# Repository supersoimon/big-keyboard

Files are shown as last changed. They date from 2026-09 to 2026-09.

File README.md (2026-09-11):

# Big Keyboard Simon V2!!!!!!!
Big Keyboard is a custom tenkeyless keyboard (87 keys) designed to fit inside a fully-3d printable case. It uses a Raspberry Pi Pico W, and connects via a Micro-USB. 

# CAD
The CAD design consists of 3 layers, using dovetail joints to hold the outer, inner, and middle layers together, while also allowing them to be easily taken apart. 





# PCB
Big Keyboard's PCB has got a couple of parts to it - a Raspberry Pi Pico (no wireless) and, diodes, and keys (pretty simple). The Diodes are SMD, while the Cherry MX keys and Pi Pico are THT.





# FIRMWARE/SOFTWARE
Pretty simple firmware, used QMK (had prior experience). Haven't coded the function of the function keys (f1, f2, etc) when not in function mode, haven't decided what I want them to do.



# Changes
Pi board was changed from SMD to THT, for easier addition

# EXTRA
Originally Big Keyboard was intentended to be a 104-key keyboard, but was pivoted to 87-key after wiring a 104-key didn't work out (matrix wasn't set up properly).
CAD was done in Onshape, PCBs done in KiCAD

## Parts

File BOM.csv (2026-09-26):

Item Name | Qty | Price (total) (USD) | Item link | Notes
PCB (Assembly, Shipping) | 1 | $41.34 | https://cart.jlcpcb.com/smt-order/?pcbFileNo=0fc75c9f361441578587309213c43a37 | JLC Parts
Keyswitches (Switches, Shipping) | 90 | $26.00 | https://www.amazon.ca/Akko-Keyboard-Dustproof-Mechanical-Switches/dp/B0C3H7PR1Z?ref_=ast_sto_dp&th=1 | Mechanical Switches (off amazon)
Keycaps Set (Caps) | 1 | $20.30 | https://www.amazon.ca/Versatile-Non-Slip-Mechanical-Ergonomic-Doubleshot/dp/B0FW4DHZVR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 | Keycaps set (off amazon)
3D Printed Parts | 1 | $0.00 |  | I print myself
Raspberry Pi Pico | 1 | $14.48 | https://www.amazon.ca/Freenove-Raspberry-Compatible-Pre-Soldered-Development/dp/B09X33TBY3 | Pi Pico board THT, also off Amazon
100 1N4148W diodes SOD-123 package |  | $3.70 | https://www.lcsc.com/product-detail/C241939.html | 100 SMD diodes
LCSC Shipping & Handling |  | $10.51
 |  | $116.33

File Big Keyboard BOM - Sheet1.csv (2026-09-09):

Item Name | Qty | Price (total) (USD) | Item link | Notes
PCB (Assembly, Shipping) | 1 | $82.74 | https://cart.jlcpcb.com/smt-order/?pcbFileNo=0fc75c9f361441578587309213c43a37 | JLC Parts & Assembly
Keyswitches (Switches, Shipping) | 90 | $36.00 | https://www.amazon.ca/Akko-Keyboard-Mechanical-Switches-Structure/dp/B0CJY7QN11 | Mechanical Switches (off amazon)
Keycaps Set (Caps) | 1 | $20.30 | https://www.amazon.ca/Versatile-Non-Slip-Mechanical-Ergonomic-Doubleshot/dp/B0FW4DHZVR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 | Keycaps set (off amazon)
3D Printed Parts | 1 | $0.00 |  | I print myself
Raspberry Pi Pico | 1 | $14.48 | https://www.amazon.ca/Freenove-Raspberry-Compatible-Pre-Soldered-Development/dp/B09X33TBY3 | Pi Pico board THT, also off Amazon
 |  | $153.52
Total Price (USD): | $307.04

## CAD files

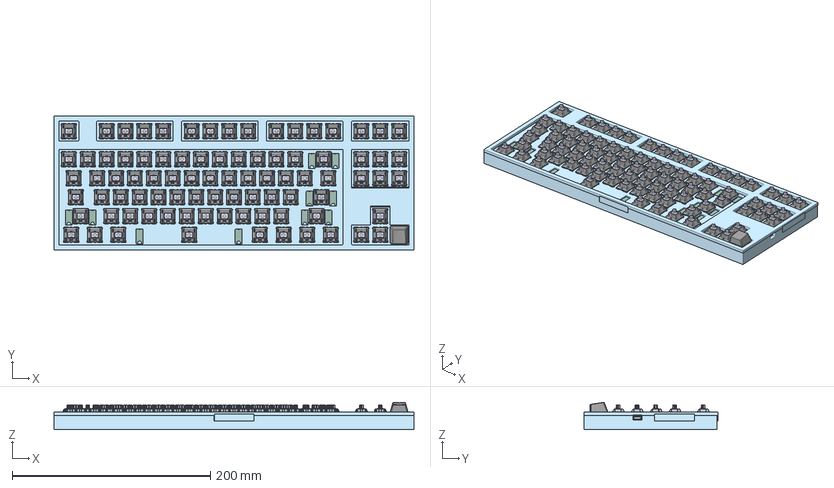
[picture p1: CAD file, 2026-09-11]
CAD/Keyboard Assembbly (1).step
363.4 x 134.8 x 27.5 mm
���___Ĭ��__��_:1__Bod y2__Õë½Å___Ä¬ÈÏ__¨¨_:1__Body2 x 87
RaspberryPi_Pico_H_Module_KiCad
���___Ĭ��__��_:1__Bod y1__Õë½Å___Ä¬ÈÏ__¨¨_:1__Body1 x 87
MX�� ���� �ײ� �̡�2 __Ĭ��_��2____��_:1__Body1 __MXÖá ÖáÌå µ×²¿ ¦Ì¡ Á2__Ä¬ÈÏ_¨¢2____¨¨_:1__Body1 x 87
D_SOD-123 x 88
MX �� ������_��_ __��1:1__Body1__MX Öá °´¼ü¡ä _¨¹___¡§1:1__Body1 x 87
MX �� ���娢��_���顧_ _:1__Body1__MX Öá ÖáÌå¨¢¨¬_¡ §¡é¡§__:1__Body1 x 87
1x1 R1 v23:1__Body2
RaspberryPi_Pico_Header_DIP-40_H2.54mm_KiCad
Simon-Big-Keyboard-V2_PCB

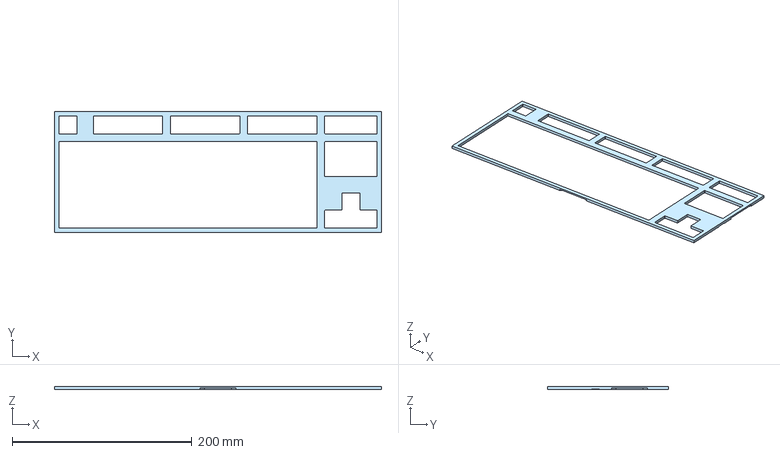
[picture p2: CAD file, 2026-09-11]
PRODUCTION/CAD FILES/Top Sheel (1).step
363.4 x 134.8 x 3.25 mm

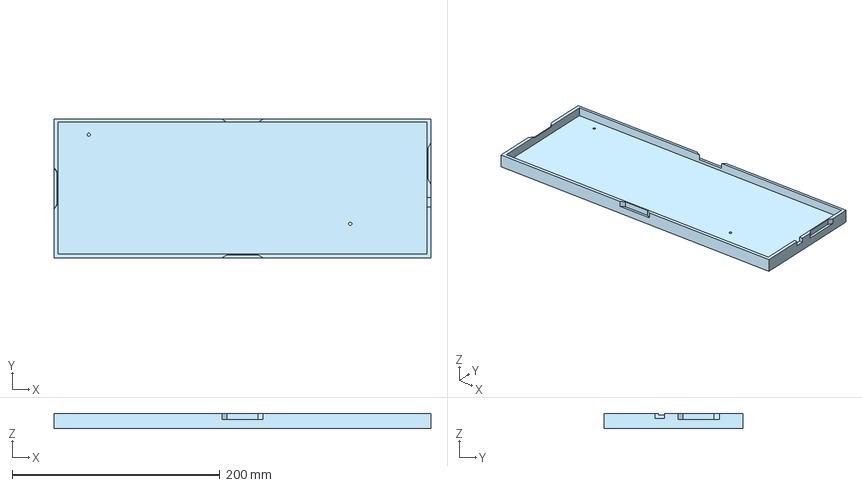
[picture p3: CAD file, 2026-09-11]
PRODUCTION/CAD FILES/bottom shell (1).step
363.4 x 133.9 x 14.5 mm

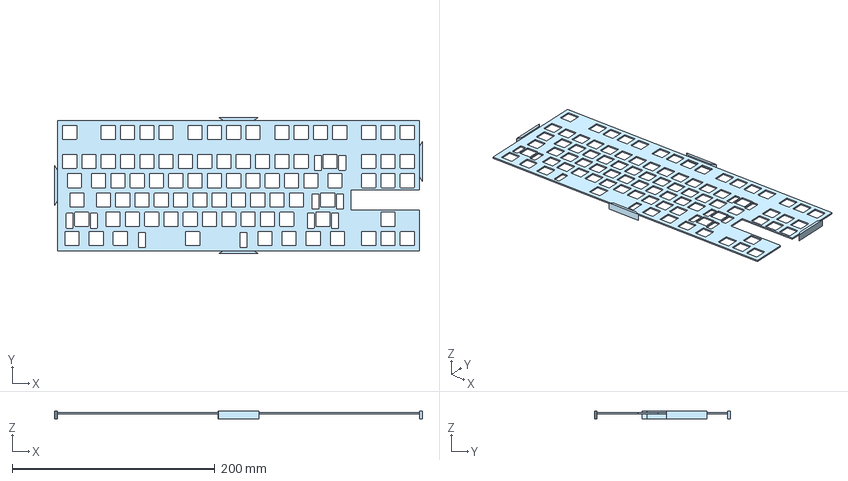
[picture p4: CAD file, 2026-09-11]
PRODUCTION/CAD FILES/Plate (1).step
363.4 x 134.8 x 7.50 mm

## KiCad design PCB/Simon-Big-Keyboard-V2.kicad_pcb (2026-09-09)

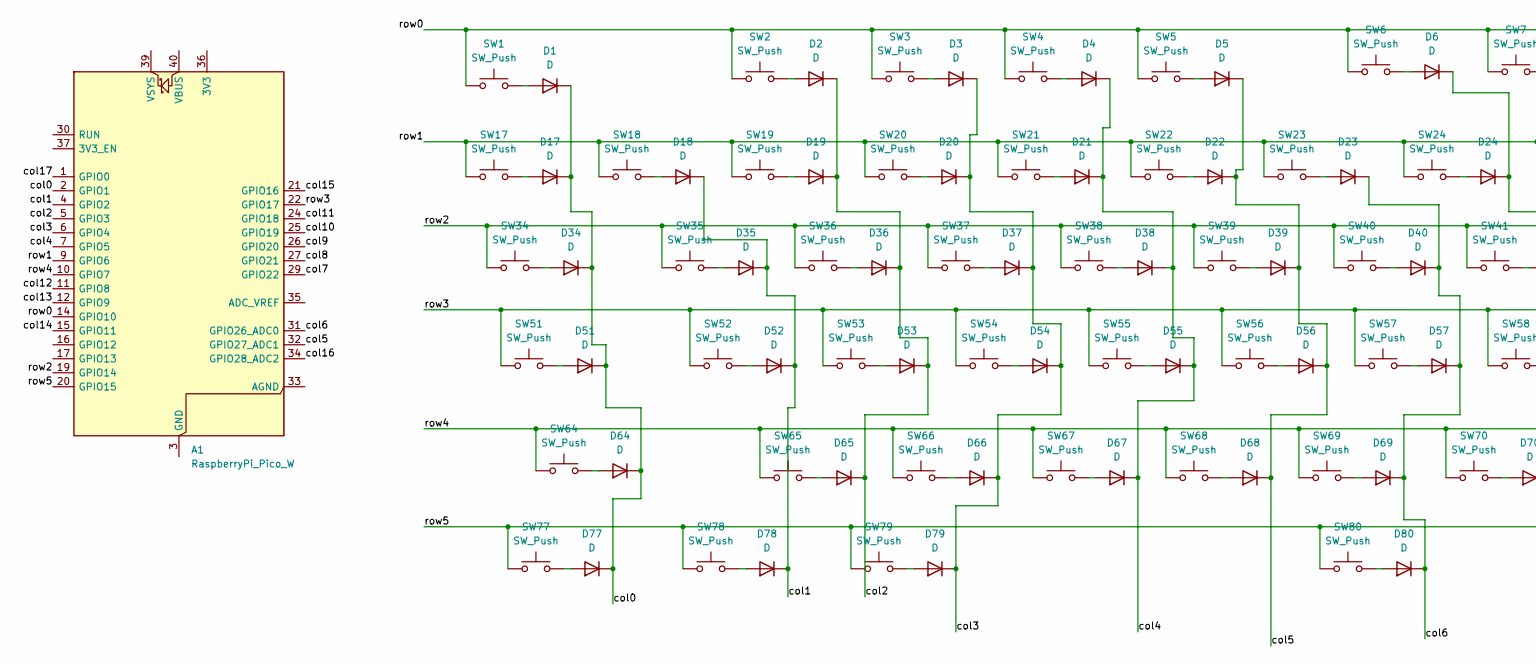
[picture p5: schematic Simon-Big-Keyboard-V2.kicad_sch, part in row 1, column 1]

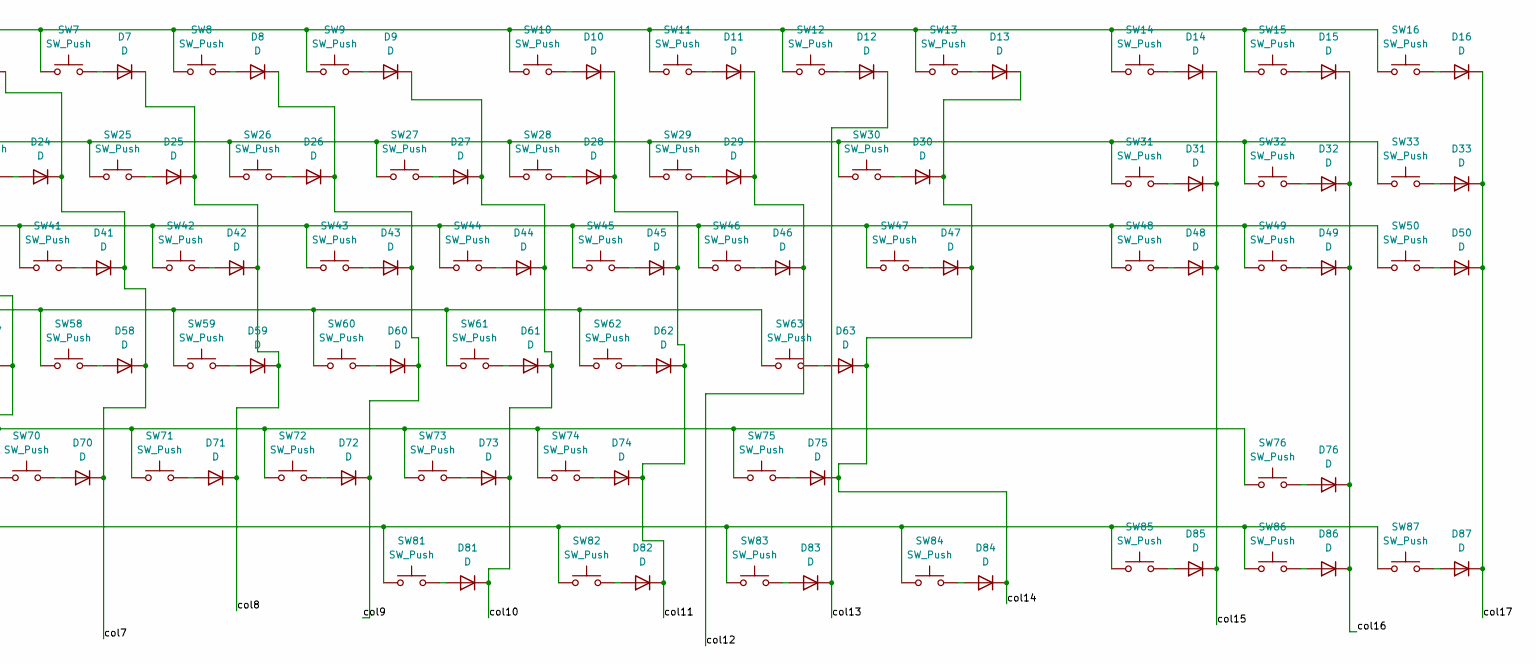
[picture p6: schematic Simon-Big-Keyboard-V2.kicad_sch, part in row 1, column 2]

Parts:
A1: RaspberryPi_Pico_W; RaspberryPi_Pico_Common_THT; JLCPCB Part # C7203002
D1, D2, D3, D4, D5, D6, D7, D8, D9, D10, D11, D12, D13, D14, D15, D16, D17, D18, D19, D20, D21, D22, D23, D24, D25, D26, D27, D28, D29, D30, D31, D32, D33, D34, D35, D36, D37, D38, D39, D40, D41, D42, D43, D44, D45, D46, D47, D48, D49, D50, D51, D52, D53, D54, D55, D56, D57, D58, D59, D60, D61, D62, D63, D64, D65, D66, D67, D68, D69, D70, D71, D72, D73, D74, D75, D76, D77, D78, D79, D80, D81, D82, D83, D84, D85, D86, D87: D; D_SOD-123; JLCPCB Part # C81598
SW1, SW2, SW3, SW4, SW5, SW6, SW7, SW8, SW9, SW10, SW11, SW12, SW13, SW14, SW15, SW16, SW17, SW18, SW19, SW20, SW21, SW22, SW23, SW24, SW25, SW26, SW27, SW28, SW29, SW31, SW32, SW33, SW35, SW36, SW37, SW38, SW39, SW40, SW41, SW42, SW43, SW44, SW45, SW46, SW48, SW49, SW50, SW52, SW53, SW54, SW55, SW56, SW57, SW58, SW59, SW60, SW61, SW62, SW65, SW66, SW67, SW68, SW69, SW70, SW71, SW72, SW73, SW74, SW76, SW85, SW86, SW87: SW_Push; SW_Cherry_MX_1.00u_PCB
SW30: SW_Push; SW_Cherry_MX_2.00u_PCB
SW34: SW_Push; SW_Cherry_MX_1.50u_Plate
SW47: SW_Push; SW_Cherry_MX_1.50u_PCB
SW51: SW_Push; SW_Cherry_MX_1.75u_PCB
SW63, SW64: SW_Push; SW_Cherry_MX_2.25u_PCB
SW75: SW_Push; SW_Cherry_MX_2.75u_PCB
SW77, SW78, SW79, SW81, SW82, SW83, SW84: SW_Push; SW_Cherry_MX_1.25u_PCB
SW80: SW_Push; SW_Cherry_MX_6.25u_PCB

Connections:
/col0: A1.2 (GPIO1), D1.1 (K), D17.1 (K), D34.1 (K), D51.1 (K), D64.1 (K), D77.1 (K)
/col1: A1.4 (GPIO2), D18.1 (K), D35.1 (K), D52.1 (K), D78.1 (K)
/col2: A1.5 (GPIO3), D2.1 (K), D19.1 (K), D36.1 (K), D53.1 (K), D65.1 (K)
/col3: A1.6 (GPIO4), D3.1 (K), D20.1 (K), D37.1 (K), D54.1 (K), D66.1 (K), D79.1 (K)
/col4: A1.7 (GPIO5), D4.1 (K), D21.1 (K), D38.1 (K), D55.1 (K), D67.1 (K)
/col5: A1.32 (GPIO27_ADC1), D5.1 (K), D22.1 (K), D39.1 (K), D56.1 (K), D68.1 (K)
/col6: A1.31 (GPIO26_ADC0), D23.1 (K), D40.1 (K), D57.1 (K), D69.1 (K), D80.1 (K)
/col7: A1.29 (GPIO22), D6.1 (K), D24.1 (K), D41.1 (K), D58.1 (K), D70.1 (K)
/col8: A1.27 (GPIO21), D7.1 (K), D25.1 (K), D42.1 (K), D59.1 (K), D71.1 (K)
/col9: A1.26 (GPIO20), D8.1 (K), D26.1 (K), D43.1 (K), D60.1 (K), D72.1 (K)
/col10: A1.25 (GPIO19), D9.1 (K), D27.1 (K), D44.1 (K), D61.1 (K), D73.1 (K), D81.1 (K)
/col11: A1.24 (GPIO18), D10.1 (K), D28.1 (K), D45.1 (K), D62.1 (K), D74.1 (K), D82.1 (K)
/col12: A1.11 (GPIO8), D11.1 (K), D29.1 (K), D46.1 (K)
/col13: A1.12 (GPIO9), D12.1 (K), D83.1 (K)
/col14: A1.15 (GPIO11), D13.1 (K), D30.1 (K), D47.1 (K), D63.1 (K), D75.1 (K), D84.1 (K)
/col15: A1.21 (GPIO16), D14.1 (K), D31.1 (K), D48.1 (K), D85.1 (K)
/col16: A1.34 (GPIO28_ADC2), D15.1 (K), D32.1 (K), D49.1 (K), D76.1 (K), D86.1 (K)
/col17: A1.1 (GPIO0), D16.1 (K), D33.1 (K), D50.1 (K), D87.1 (K)
/row0: A1.14 (GPIO10), SW1.1, SW2.1, SW3.1, SW4.1, SW5.1, SW6.1, SW7.1, SW8.1, SW9.1, SW10.1, SW11.1, SW12.1, SW13.1, SW14.1, SW15.1, SW16.1
/row1: A1.9 (GPIO6), SW17.1, SW18.1, SW19.1, SW20.1, SW21.1, SW22.1, SW23.1, SW24.1, SW25.1, SW26.1, SW27.1, SW28.1, SW29.1, SW30.1, SW31.1, SW32.1, SW33.1
/row2: A1.19 (GPIO14), SW34.1, SW35.1, SW36.1, SW37.1, SW38.1, SW39.1, SW40.1, SW41.1, SW42.1, SW43.1, SW44.1, SW45.1, SW46.1, SW47.1, SW48.1, SW49.1, SW50.1
/row3: A1.22 (GPIO17), SW51.1, SW52.1, SW53.1, SW54.1, SW55.1, SW56.1, SW57.1, SW58.1, SW59.1, SW60.1, SW61.1, SW62.1, SW63.1
/row4: A1.10 (GPIO7), SW64.1, SW65.1, SW66.1, SW67.1, SW68.1, SW69.1, SW70.1, SW71.1, SW72.1, SW73.1, SW74.1, SW75.1, SW76.1
/row5: A1.20 (GPIO15), SW77.1, SW78.1, SW79.1, SW80.1, SW81.1, SW82.1, SW83.1, SW84.1, SW85.1, SW86.1, SW87.1
unnamed: A1.3 (GND), A1.8 (GND), A1.13 (GND), A1.18 (GND), A1.23 (GND), A1.28 (GND), A1.38 (GND)
unnamed: D1.2 (A), SW1.2
unnamed: D2.2 (A), SW2.2
unnamed: D3.2 (A), SW3.2
unnamed: D4.2 (A), SW4.2
unnamed: D5.2 (A), SW5.2
unnamed: D6.2 (A), SW6.2
unnamed: D7.2 (A), SW7.2
unnamed: D8.2 (A), SW8.2
unnamed: D9.2 (A), SW9.2
unnamed: D10.2 (A), SW10.2
unnamed: D11.2 (A), SW11.2
unnamed: D12.2 (A), SW12.2
unnamed: D13.2 (A), SW13.2
unnamed: D14.2 (A), SW14.2
unnamed: D15.2 (A), SW15.2
unnamed: D16.2 (A), SW16.2
unnamed: D17.2 (A), SW17.2
unnamed: D18.2 (A), SW18.2
unnamed: D19.2 (A), SW19.2
unnamed: D20.2 (A), SW20.2
unnamed: D21.2 (A), SW21.2
unnamed: D22.2 (A), SW22.2
unnamed: D23.2 (A), SW23.2
unnamed: D24.2 (A), SW24.2
unnamed: D25.2 (A), SW25.2
unnamed: D26.2 (A), SW26.2
unnamed: D27.2 (A), SW27.2
unnamed: D28.2 (A), SW28.2
unnamed: D29.2 (A), SW29.2
unnamed: D30.2 (A), SW30.2
unnamed: D31.2 (A), SW31.2
unnamed: D32.2 (A), SW32.2
unnamed: D33.2 (A), SW33.2
unnamed: D34.2 (A), SW34.2
unnamed: D35.2 (A), SW35.2
unnamed: D36.2 (A), SW36.2
unnamed: D37.2 (A), SW37.2
unnamed: D38.2 (A), SW38.2
unnamed: D39.2 (A), SW39.2
unnamed: D40.2 (A), SW40.2
unnamed: D41.2 (A), SW41.2
unnamed: D42.2 (A), SW42.2
unnamed: D43.2 (A), SW43.2
unnamed: D44.2 (A), SW44.2
unnamed: D45.2 (A), SW45.2
unnamed: D46.2 (A), SW46.2
unnamed: D47.2 (A), SW47.2
unnamed: D48.2 (A), SW48.2
unnamed: D49.2 (A), SW49.2
unnamed: D50.2 (A), SW50.2
unnamed: D51.2 (A), SW51.2
unnamed: D52.2 (A), SW52.2
unnamed: D53.2 (A), SW53.2
unnamed: D54.2 (A), SW54.2
unnamed: D55.2 (A), SW55.2
unnamed: D56.2 (A), SW56.2
unnamed: D57.2 (A), SW57.2
unnamed: D58.2 (A), SW58.2
unnamed: D59.2 (A), SW59.2
unnamed: D60.2 (A), SW60.2
unnamed: D61.2 (A), SW61.2
unnamed: D62.2 (A), SW62.2
unnamed: D63.2 (A), SW63.2
unnamed: D64.2 (A), SW64.2
unnamed: D65.2 (A), SW65.2
unnamed: D66.2 (A), SW66.2
unnamed: D67.2 (A), SW67.2
unnamed: D68.2 (A), SW68.2
unnamed: D69.2 (A), SW69.2
unnamed: D70.2 (A), SW70.2
unnamed: D71.2 (A), SW71.2
unnamed: D72.2 (A), SW72.2
unnamed: D73.2 (A), SW73.2
unnamed: D74.2 (A), SW74.2
unnamed: D75.2 (A), SW75.2
unnamed: D76.2 (A), SW76.2
unnamed: D77.2 (A), SW77.2
unnamed: D78.2 (A), SW78.2
unnamed: D79.2 (A), SW79.2
unnamed: D80.2 (A), SW80.2
unnamed: D81.2 (A), SW81.2
unnamed: D82.2 (A), SW82.2
unnamed: D83.2 (A), SW83.2
unnamed: D84.2 (A), SW84.2
unnamed: D85.2 (A), SW85.2
unnamed: D86.2 (A), SW86.2
unnamed: D87.2 (A), SW87.2

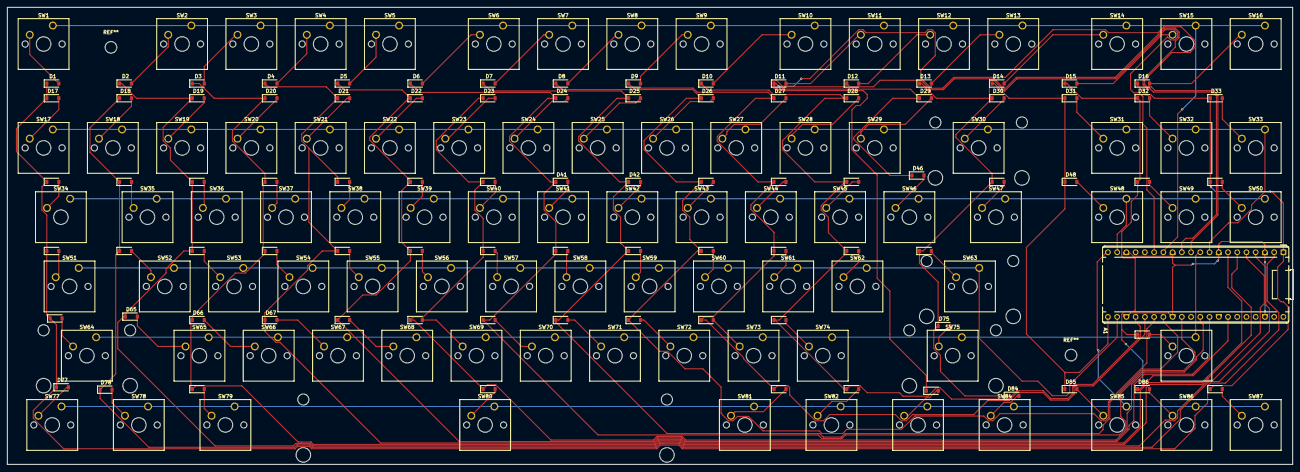
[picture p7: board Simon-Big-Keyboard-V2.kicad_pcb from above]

Board: 2 copper layers, 353.5 x 125.7 mm, 175 parts (0 on the bottom side), 112 nets.

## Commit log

2026-08-26 Refactor code structure for improved readability and maintainability
    [Keyboard Assembbly.step, Plate.step, Top Sheel.step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]
2026-08-26 added PCB electrical files
    [Simon-Big-Keyboard-V2.kicad_pcb, Simon-Big-Keyboard-V2.kicad_sch]
2026-08-27 reorganized CAD files
    [Plate.step, Top Sheel.step, bottom shell.step]
2026-08-27 added gerber pcb files
2026-08-27 Update README with project details for Big Keyboard
    Added detailed project description, including CAD, PCB, firmware, and extra information about the Big Keyboard.
2026-08-27 Added Gerber Files with Drill Holes
2026-09-09 Rename Big Keyboard BOM - Sheet1.csv to BOM.csv
    [BOM.csv]
2026-10-30 Clarify Raspberry Pi and PCB component details
    Updated the description of the Raspberry Pi used in the Big Keyboard project and clarified the SMD/THT components in the PCB section. Removed the 'Changes' section as it was no longer relevant.
2026-10-30 Update BOM.csv with new items and prices
